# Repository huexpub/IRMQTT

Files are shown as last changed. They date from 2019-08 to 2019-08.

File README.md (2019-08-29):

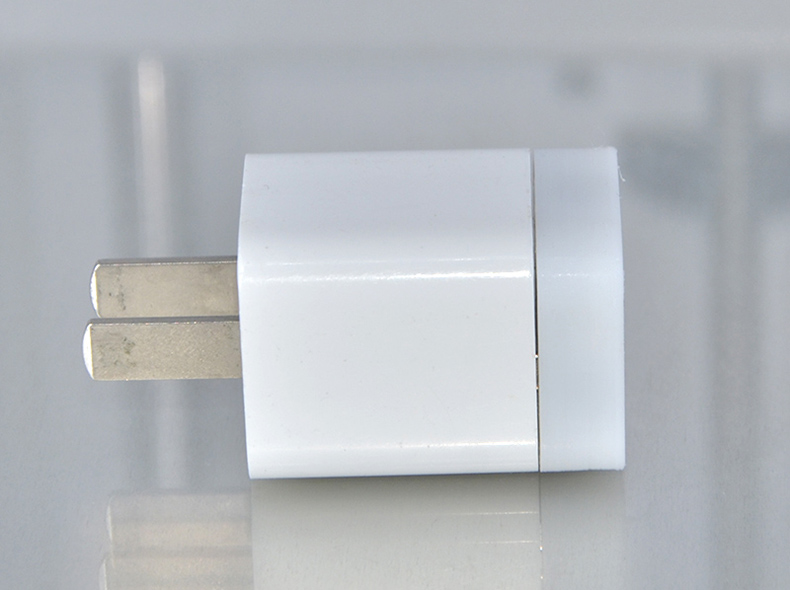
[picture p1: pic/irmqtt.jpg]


>>> 2019-08-29更新了可反馈性WEB使用说明及识别品牌

## 声明：
1. IRMQTT 是一个开源项目，源代码来自https://github.com/crankyoldgit/IRremoteESP8266，
2. IRMQTT PCB你可以自由的使用，并且制作分享与朋友交流，但严禁商业行为!

IRMQTT首贴：
https://bbs.iobroker.cn/thread-176-1-1.html

IRMQTT模块贴：
https://bbs.iobroker.cn/thread-221-1-1.html

IRMQTT支持列表：
https://github.com/crankyoldgit/IRremoteESP8266/blob/master/SupportedProtocols.md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

## 准备工作：
此次PCB模块为适应更高的通用性，以苹果绿点5V1A充电器为供电对象，最小化PCB板和硬件体积，合体后仅增加7.2mm的高度，一体感非常好!  由于体积定位，元件大量采用0402贴片，PCB面积仅21*20MM。

### PCB
本次PCB文件单体制造难度较大，新手尽量转移到ESP12F项目和ESP01F改装模块！高手可进

项目地址: https://github.com/huexpub/IRMQTT

* 分支包含ESP01F文件和ESP12F文件，默认为IRMQTT USB公插版本，
* 固件目前测试可以通用，如果内部为ESP01F，会有OTA文件限制！
* 刷机均需要1.27夹具或者焊接线材

### 贴装
PCB贴装，请控制好你的烙铁温度，保持300以内，针对发射贴片，请避免长时间操作

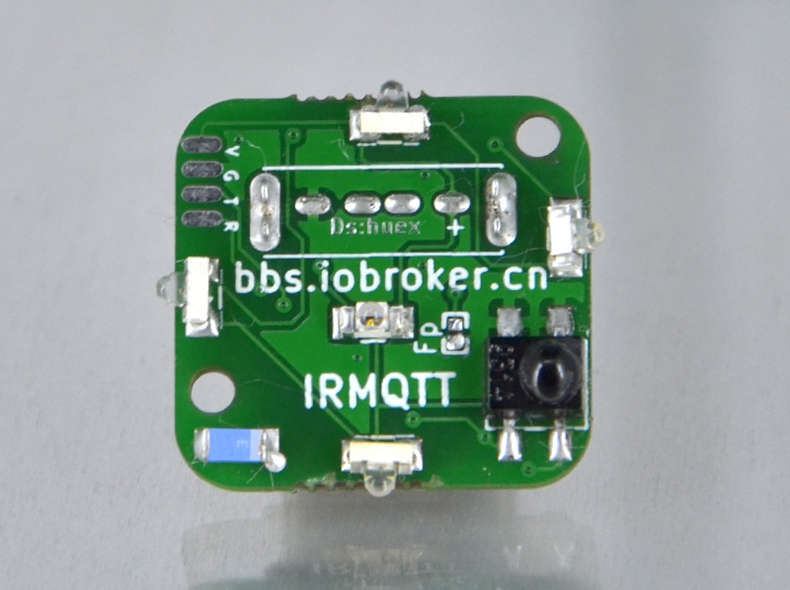
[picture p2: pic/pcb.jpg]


* 保持发射贴片丝印标记正确，除中心发射元件，其它保持45度角以得到更好的发射范围
* 由于接收元件外露在3D外壳之外，请确保元件正中，否则外壳无法安装

### 刷机

由于空间较小，刷机TTL为4P*1.27MM 故，你需要特殊的工具，比SOP8，SOP16刷机夹，1.27测试针，或者自己焊接线刷机，刷机后，后期均由OTA完成更新！PCB正面，FP脚为0-GND的短接点，短接后，ESP进入下载模式，刷机完成后，请去除短接！

### 3D
 3D外壳为上、下沉方式，需要M2沉头螺丝两颗，目前设计的螺丝帽直径最大为4.5MM 沉头内六角螺丝。
 
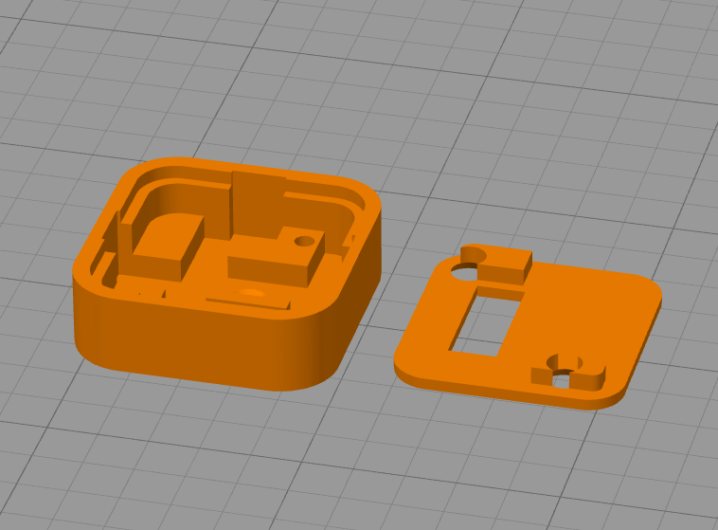
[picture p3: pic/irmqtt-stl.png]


## 安装使用：
软件采用WIFIMANAGER配网，上电后，搜索IRMQTT热点，连接上，转入配网WEB页面，未弹出请尝试访问192.168.4.1地址

### 配网

>请务必保证MQTT服务器地址正确，否则可能无法进入WEB页面，并且无法重新配置！

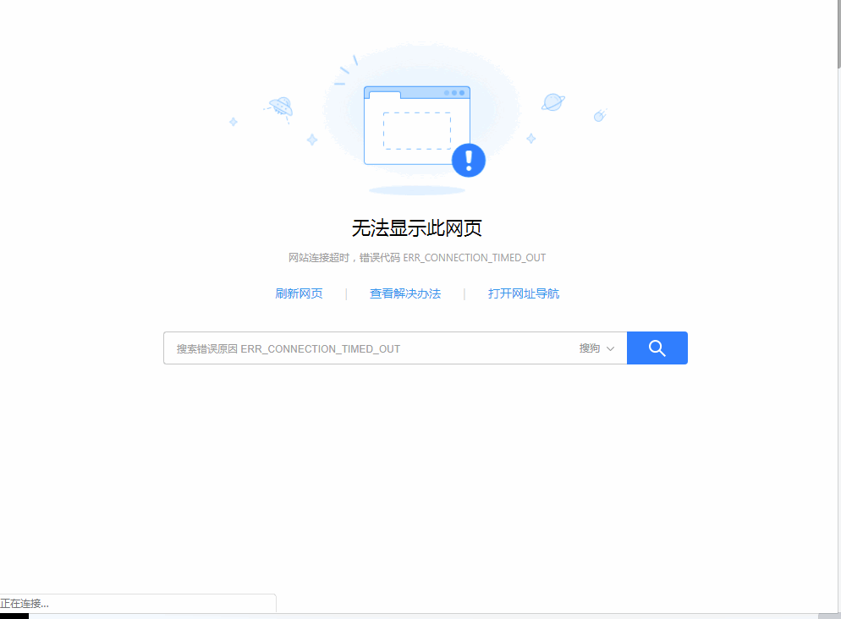
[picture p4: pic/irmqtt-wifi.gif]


### 使用
进入配置的IRMQTT设备IP WEB，页面如下：

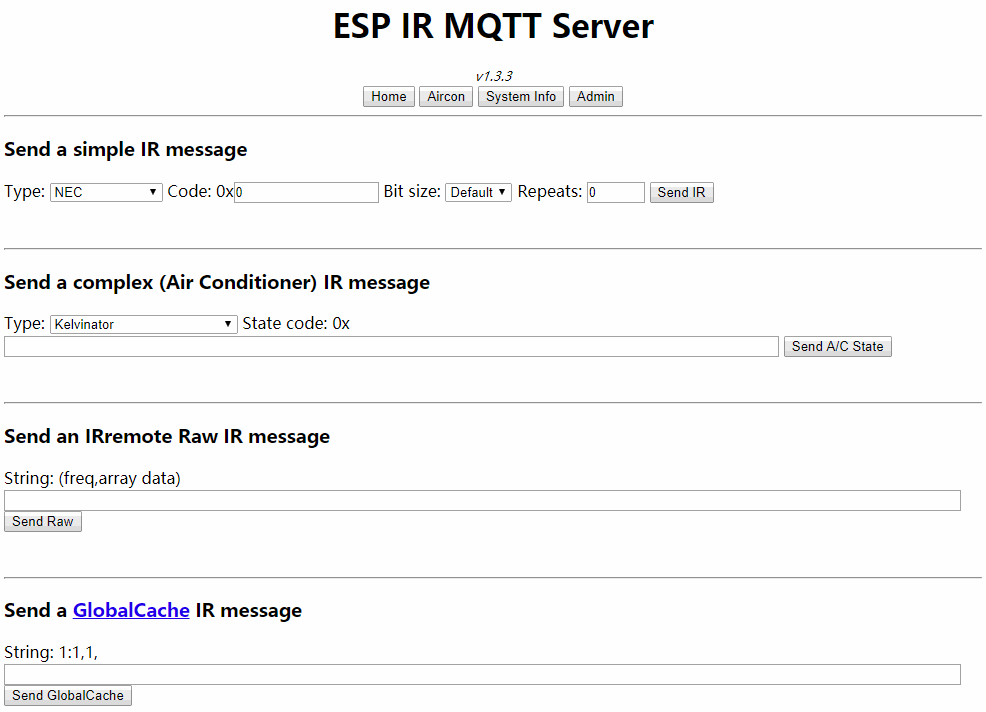
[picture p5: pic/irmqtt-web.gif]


选择对应的空调型号，模式，电源，温度，并点击 UPDATE/SEND，空调有反应后，视为有效型号，若无反应，请对应尝试model 1-6子设备型号，如均无反应，可能不被支持。

### 反馈
如何知道IRMQTT模块是否已经能正常的反馈呢，你可以使用MQTT工具监听。如下图GIF演示！

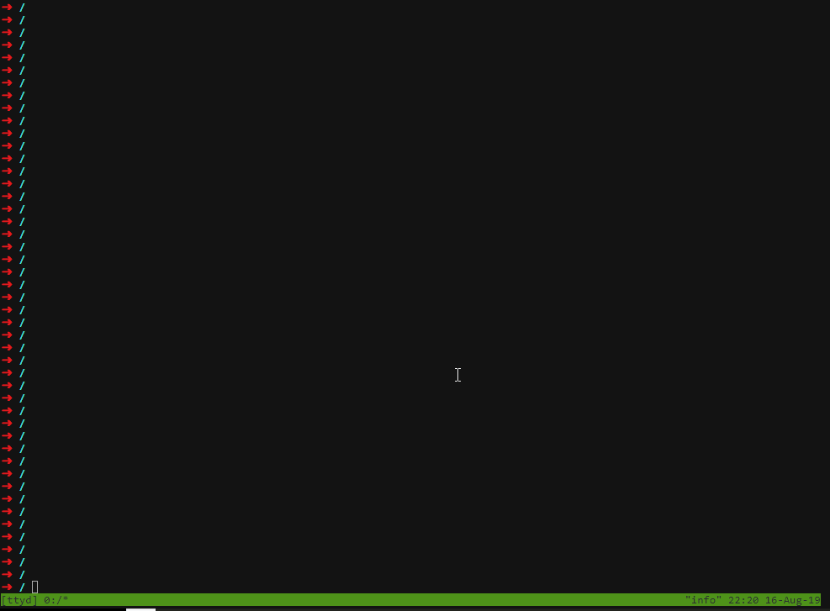
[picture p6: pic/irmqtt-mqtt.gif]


*  默认连接上MQTT后，出来的型号和设备等是默认生成的，不是接收到的
* 操作之后能出现ON OFF和有效的数据源，视为可反馈，
* 关于监听工具，你可以使用docker 镜像  huex/webzsh:armbian (https://mysensor.pub/gateway/webzsh/)

### 识别

```
enum decode_type_t {
  UNKNOWN = -1,
  UNUSED = 0,
  RC5,
  RC6,
  NEC,
  SONY,
  PANASONIC,  // (5)
  JVC,
  SAMSUNG,
  WHYNTER,
  AIWA_RC_T501,
  LG,  // (10)
  SANYO,
  MITSUBISHI,
  DISH,
  SHARP,
  COOLIX,  // (15)
  DAIKIN,
  DENON,
  KELVINATOR,
  SHERWOOD,
  MITSUBISHI_AC,  // (20)
  RCMM,
  SANYO_LC7461,
  RC5X,
  GREE,
  PRONTO,  // Technically not a protocol, but an encoding. (25)
  NEC_LIKE,
  ARGO,
  TROTEC,
  NIKAI,
  RAW,  // Technically not a protocol, but an encoding. (30)
  GLOBALCACHE,  // Technically not a protocol, but an encoding.
  TOSHIBA_AC,
  FUJITSU_AC,
  MIDEA,
  MAGIQUEST,  // (35)
  LASERTAG,
  CARRIER_AC,
  HAIER_AC,
  MITSUBISHI2,
  HITACHI_AC,  // (40)
  HITACHI_AC1,
  HITACHI_AC2,
  GICABLE,
  HAIER_AC_YRW02,
  WHIRLPOOL_AC,  // (45)
  SAMSUNG_AC,
  LUTRON,
  ELECTRA_AC,
  PANASONIC_AC,
  PIONEER,  // (50)
  LG2,
  MWM,
  DAIKIN2,
  VESTEL_AC,
  TECO,  // (55)
  SAMSUNG36,
  TCL112AC,
  LEGOPF,
  MITSUBISHI_HEAVY_88,
  MITSUBISHI_HEAVY_152,  // 60
  DAIKIN216,
  SHARP_AC,
  GOODWEATHER,
  INAX,
  DAIKIN160,  // 65
  NEOCLIMA,
  DAIKIN176,
  DAIKIN128,
  AMCOR,
  DAIKIN152,  // 70
  
```

以上为可识别的代码列表，你可以进入IRMQTT-WEB页面 SYSTEM-INFO页 找到 Last IR Received: 47,0,0 (9 hours 53 minutes 58 seconds ago)

得到47,0,0 代表是得到47序号的对应品牌属性值，对照上文，为LUTRON，部分空调反馈的品牌未必是品牌自身对应，这可能是该品牌有代工或者被代工的。如果是其它家用电器，电视等，这些基本被统一，多数为三星，索尼，松下协议或者标准RC协议不必对照本身品牌！

### 接入
由于采用标准MQTT协议，并且作者以Homeassistant为蓝本输出消息，故，你可以使用IRMQTT-WEB控制台发送 MQTT discovery 让平台自动发现即可，也可以手动配置，配置如下：

```

climate:
  - platform: mqtt
    name: zwaircon
    modes:
      - "off"
      - "auto"
      - "cool"
      - "heat"
      - "dry"
    fan_modes:
      - "auto"
      - "min"
      - "low"
      - "medium"
      - "high"
      - "max"
    swing_modes:
      - "off"
      - "auto"
      - "highest"
      - "high"
      - "middle"
      - "low"
    power_command_topic: "ir_server/ac/cmnd/power"
    mode_command_topic: "ir_server/ac/cmnd/mode"
    mode_state_topic: "ir_server/ac/stat/mode"
    temperature_command_topic: "ir_server/ac/cmnd/temp"
    temperature_state_topic: "ir_server/ac/stat/temp"
    fan_mode_command_topic: "ir_server/ac/cmnd/fanspeed"
    fan_mode_state_topic: "ir_server/ac/stat/fanspeed"
    current_temperature_topic: "tele/bksensor/SENSOR"
    current_temperature_template: "{{ value_json['SI7021'].Temperature }}"
    swing_mode_command_topic: "ir_server/ac/cmnd/swingv"
    swing_mode_state_topic: "ir_server/ac/stat/swingv"
    min_temp: 16
    max_temp: 30
    temp_step: 1
    retain: false
    
```
*  current_temperature_topic 和 current_temperature_template 为外部引用温度，这里采用了JSON格式的消息
*  请依据你的空调实际情况修改对应的菜单

### OTA
由于ESP01F flash只有1MB，实际固件不能超过467KB，但由于按开源编译，固件至少490K，造成由于空间不够无法在线更新，故我们只能曲线升级，在不破坏SPIIFS的情况下，先上传一个只有WEB-UPDATE功能的迷你型固件，该固件也采用WIFIMANAGER配置 网，并且能继承原有配置，升级后重新打开IP，进入WEB，选择最新的IMQTT固件升级即可

总结即： OTA--MINI 固件--正常固件

以下为演示：
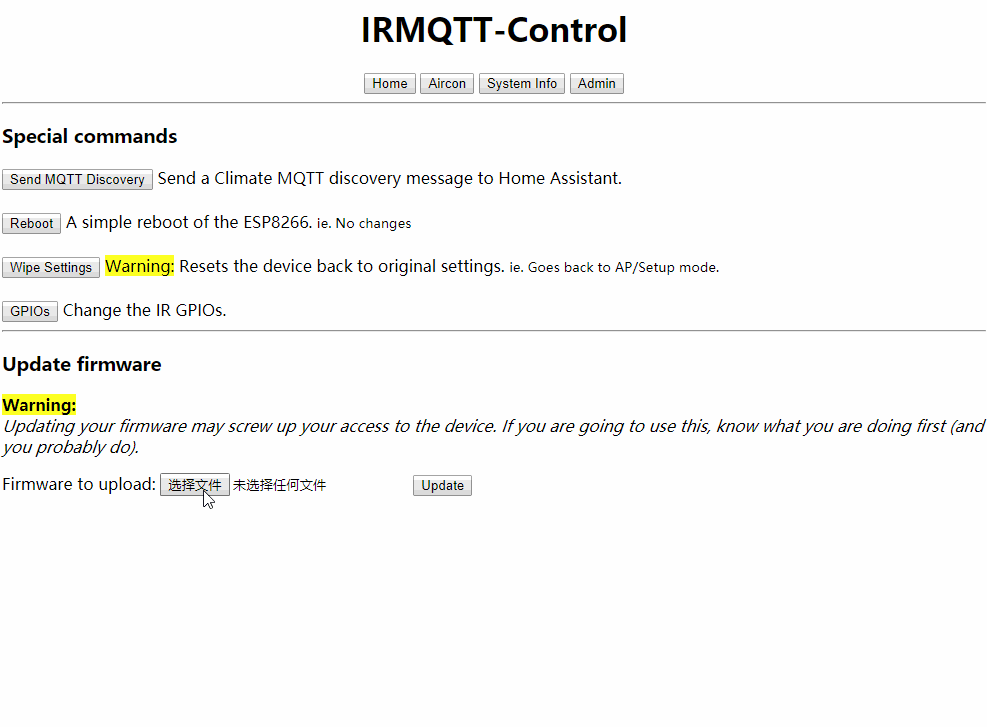
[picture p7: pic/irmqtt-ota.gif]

  
## SMT开车
  此次为了方便各位，目前已经将PCB 容阻元件、三极管、LED、LDO 采用 SMT 小批量产，到手只需要焊接发射元件、接收元件、USB、天线贴片、ESP01，极容易操作的元件部分！方便能DIY并且有3D打印机的小伙伴!
  
链接：https://item.taobao.com/item.htm?spm=a1z10.1-c.w4023-7677041950.2.57033a0cMouRqm&id=600537216286

*  成品涉及到3D打印，由于打印消耗时间和人工，故发货时间7天内
*  淘宝不经常在线，如果你有疑问和好的建议尽量在论坛或者ioBroker群MYSENSOR群@HUEX

## Q&A

- 1.购买单PCB文件，我还要购买哪些材料？
A: 安信可ESP01F 、BOM表中的EVERLIGHT台产亿光 IR26-61C 发射贴片、接收元件H638T，2.4G天线RFANT3216-Z。

- 2.空调在列表中，但无法发射？
A: 请先使用MQTT监测是否遥控有接收到数据，如果有数据，那么你发射的型号可能不对，特别是像美的，格力，等在海外有代工或者授权品牌，采用的，你可能需要使用其它品牌型号，比如COOLIX、ELECTRA_AC等。如果你接收都没有任何消息，那么很遗憾，至少源码暂时可能无法支持。

- 3.部分操作码不正常？
A: 出现这个情况，你可以尝试更换其它MODEL试试，1-6每个都试一下，如果问题依然，那么需要向作者提交ISSUES来解决，你需要提交原始码，原始操作，有差异化的信息，然后一并提交，具体提交办法你可以参考作者源码的入口。

- 4.有支持其它电源吗？
A. 理论上体积大于25*25mm的电源都可以3D画图解决，但手头暂时无其它电源，也没有额外的精力设计制作，暂时不扩充，你可以自行设计！

- 5.固件我可以自己编译上传吗？
A.没有问题，按上述OTA操作，先上传MINI固件，然后上传最新的即可。

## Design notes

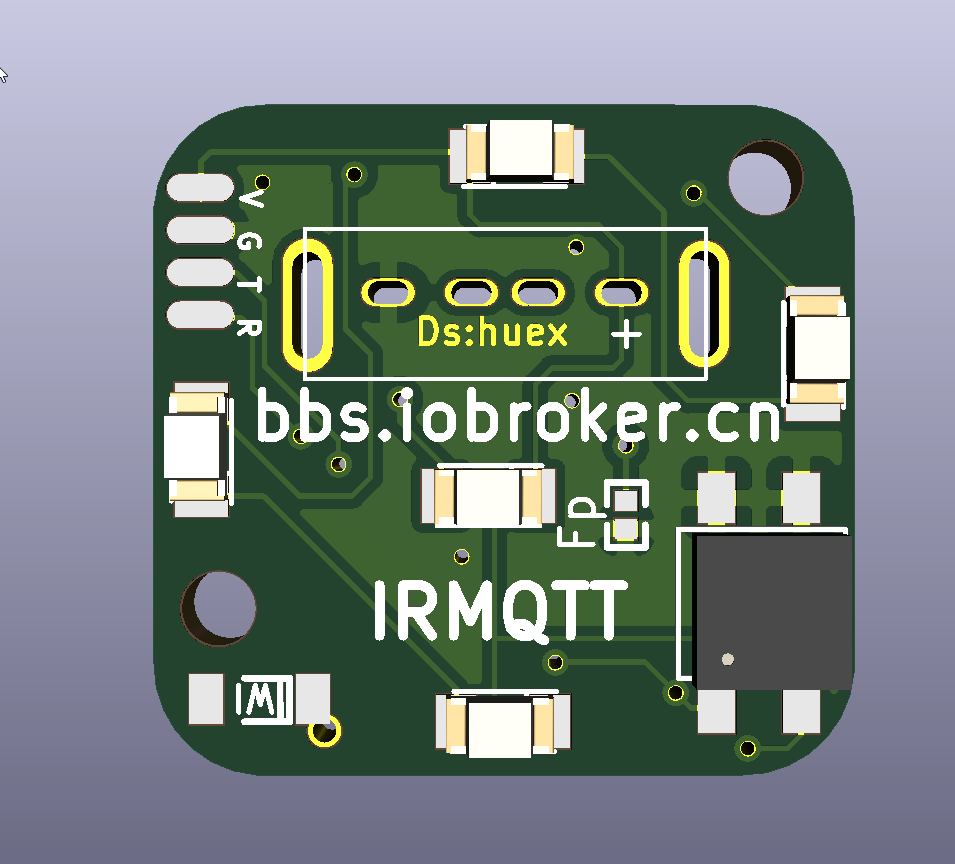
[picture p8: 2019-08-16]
pcb.png

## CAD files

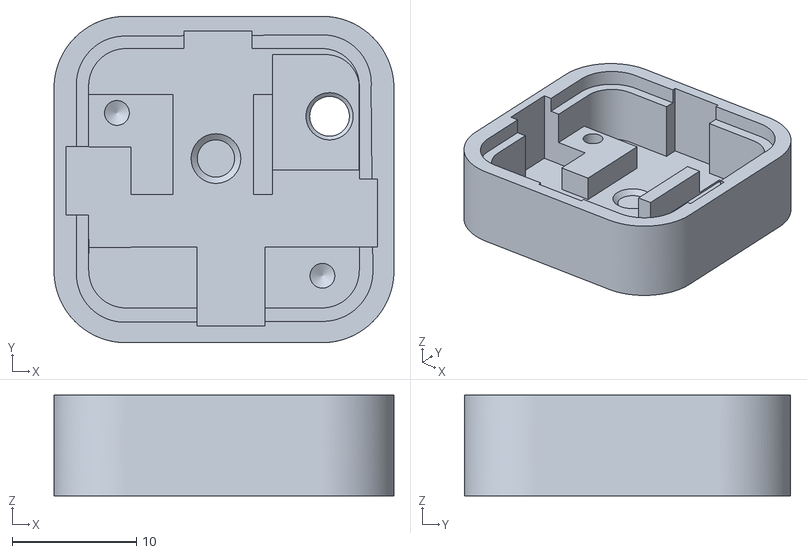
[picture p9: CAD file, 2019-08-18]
stl/PIR v69.stl
27.4 x 26.3 x 8.10

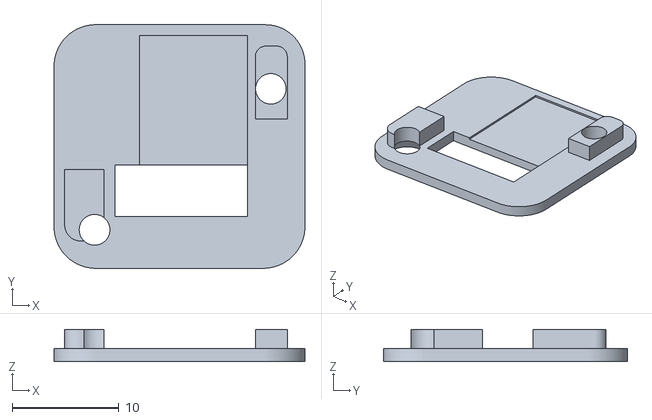
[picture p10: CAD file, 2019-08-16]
stl/IR-B v30.stl
23.5 x 22.8 x 3.00

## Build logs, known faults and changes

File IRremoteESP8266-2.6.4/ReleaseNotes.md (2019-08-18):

# Release Notes

## _v2.6.4 (20190726)_

**[Bug Fixes]**
- Fix some swing problems with the Mitsubishi HAVC protocol (#831)
- Fix parameter ordering for Gree in common a/c code. (#815)
- Fix parameters for Coolix in IRac::sendAc() (#829)
- IRMQTTServer: Fix sending >64 bit codes. (#811)

**[Features]**
- Daikin128: Full detailed support & common a/c support. (#832)
- Midea: Support native temp units of Celsius & SwingV. (#823)
- Gree: Support `YBOFB` models and bug fix. (#815)
- Pioneer: Fix sendPioneer with Pioneer specific timings (#830)
- Daikin128: Initial support for Daikin 17 Series/BRC52B63 (#828)
- Coolix: Better `toCommon()` support. (#825)
- Experimental detailed support for Daikin 176 bits (#816)
- Add setting of output options to A/C classes. (#808)
- Add invert flag support to Samsung AC (#807)

**[Misc]**
- Daikin176: making some change on Daikin176 to work with IRMQTTServer (#826)
- Reduce duplicate code to save (3K+) space. (#813)
- Daikin176: Experiment Daikin176bits with IRMQTTServer (#824)
- Update platformio.ini files for PlatformIO v4.0.0 (#812)
- Change repo URLs to new location. (#806)
- Move `htmlEscape()` to the IRutils namespace (#801)

## _v2.6.3 (20190704)_

**[Bug Fixes]**
- IRMQTTServer: REPLAY_DECODED_AC_MESSAGE not working. (#784, #797)
- ESP32: Ensure `IRrecv`'s GPIO is set to input mode. (#774)

**[Features]**
- IRMQTTServer: Show available sketch space for OTA uploads. (#795)
- Experimental detailed support for Electra/AUX protocol (#788)
- IRMQTTServer: Ability to resend existing climate state via MQTT & HTTP (#784)
- Daikin160: Add detailed & common a/c support. (#777)
- Experimental detailed support for Neoclima protocol. (#767)
- Gree: add WiFi and IFeel bits (#770)
- Handle A/Cs with toggles better. (#758)
- IRMQTTServer: Allow sending/receiving climate via JSON over MQTT. (#763)

**[Misc]**
- Move converting of IR A/C messages out of example code. (#798)
- Reduce example code size and complexity (#790)
- Change `ControlSamsungAC` example to not use `sendExtended()` (#792)
- IRMQTTServer: Add MQTT_CLIMATE_IR_SEND_ON_RESTART compile-time flag. (#784)
- Refactor A/C's toString()'s to reduce code size. Saves ~3.5k (#782)
- Add sanity tests for unexpected conditions in IRrecv. (#773)
- IRMQTTServer: Fixed the HA config documentation (missing '-') (#776)
- Improve `mkkeywords` tool. (#766)
- Refactor with generic decode routines in `IRrecv` class. Saves ~7k. (#765)

## _v2.6.2 (20190616)_

**[Features]**
- Initial support for the ESP32 architecture & boards. (#742)
- Add changable GPIO settings to IRMQTTServer. (#730)
- IRMQTTServer: Enforce a repeat for all Coolix calls (#752)
- Basic DAIKIN 160bit send and decode. (#754)
- Add example code for a Smart(er) IR Repeater. (#740)
- Enforce Samsung A/C Quiet & Powerful mutual exclusivity.

**[Misc]**
- IRMQTTServer: Add some memory alloc safety checks. (#749)
- Move some ToString() functions to IRac.cpp (#748)
- Increase tolerance value for TCL112AC protocol. (#745)
- Fix compiler warning in IRutils_test.cpp (#756)
- Scrape Supported Protocols and generate SupportedProtocols.md (#755)
- Make supported device info more organised. (#753)

## _v2.6.1 (20190609)_

**[Breaking Changes]**
- Major rework/breaking changes to Argo A/C support. (#705)

**[Bug Fixes]**
- Correct `set/getQuiet` for Samsung A/C (#736)
- Add missing `on/off()` to IRCoolixAC class. (#725)
- Daikin `set/getEye()` uses wrong bit. (#711)
- IRMQTTServer: Continue to use same Temperature units. (#710)
- Fixed a bug with `setMode()`/`getMode()` for HAIER_AC. (#705)

**[Features]**
- Add set/getPowerful for Samsung A/C (#736)
- Add `calibrate()` to all the A/C classes. (#735)
- IRMQTTServer: Add sequencing for sending MQTT IR commands. (#723)
- Add support for Fujitsu AR-REB1E & AR-JW2 remotes. (#718)
- Add Beta `decodeTrotec()` support. (#719)
- Add experimental `decodeArgo()` support. (#717)
- Support for Goodweather A/Cs. (#715)
- Add `DISABLE_CAPTURE_WHILE_TRANSMITTING` feature to IRMQTTServer. (#713)
- Support for Lixil Inax Toilet protocol. (#712)
- Add `set/getWeeklyTimerEnable()` to Daikin (#711)
- IRMQTTServer: Update Common A/C settings based on received IR messages. (#705)
- Add day of week to DAIKIN protocol (#699)
- Add limited support for Sharp A/C (#696)
- SAMSUNG_AC: Make sure special power mode messages are sent. (#695)
- Add `set/getPowerful()` (turbo) to DAIKIN216 (#693)

**[Misc]**
- Add kPeriodOffset for CPU Freq of 160MHz. (#729)
- Example code for a Dumb IR repeater. (#737)
- Update swing handling for Fujitsu A/Cs. (#724)
- Add function to convert `decode_results` to `sendRaw()` array. (#721)
- Attempt to reduce heap fragmentation from strings. (#707)
- Update Fujitsu A/C example code to safer settings (#716)
- Enforce better `const` usage in IRUtils. (#708)
- Attempt to reduce heap fragmentation by A/C `toString()`s. (#694)
- Minor changes to DAIKIN216 timings and features. (#693)

## _v2.6.0 (20190430)_

**[Bug Fixes]**
- Fixed problem where LG protocol used wrong duty cycle for repeat. (#687)
- Fix checksum calculation for Daikin protocols. (#678)
- Fix the byte array version of sendGree() (#684, #685)
- Fix artificial vs. real state creation on HaierAC. (#668, #671)
- Fix issues caused by having `MQTT_ENABLE` set to false. (#677)
- Fix compile problem when DEBUG is defined. (#673, #674)
- Fix Minor bug with MQTT_ENABLE False condition (#654)

**[Features]**
- Experimental support for DAIKIN216 (ARC433B69) (#690)
- Experimental support for Mitsubishi Heavy Industries A/Cs. (#660, #665, #667)
- Support more features of TCL A/C (#656)
- Add LEGO(TM) Power Functions IR protocol. (#655)
- Add Panasonic AC RKR model & Example (#649)
- DAIKIN/IRDaikinESP overhaul and add Comfort mode support. (#678)
  **WARNING**: Previous `sendDaikin()` calls may not work.
               Please recapture codes or use `kDaikinStateLengthShort` for
               `nbytes` in those calls.
- IRMQTTServer: Move MQTT server and other parameters to WifiManager. (#680)
  **WARNING**: Previous users may need to fully wipe/reset the
               SPIFFS/WifiManager settings by visiting
               `http://<your_esp8266's_ip_address>/reset` prior to or
               after update.
- Add Wifi filtering options to IRMQTTServer. (#679)
- Add advanced aircon/climate functionality to IRMQTTServer (#677)
- Initial prototype of a common interface for all A/Cs. (#664)
- Improve MQTT topic usage for feedback messages. (#663)
- Add multiple independent GPIO sending support via MQTT. (#661)

**[Misc]**
- Adjust kGreeHdrSpace to 4500 (#684, #686)
- Add Home Assistant mqtt climate instructions. (#682)
- Implement htmlEscape() to prevent XSS etc. (#681)
- Add F() Macros (#670)
- Update Daikin2's Cool mode min temp to 18C (#658)
- Change per byte bit-order in Electra protocol. (#648)
- Improve Daikin2 power on/off. (#647)

## _v2.5.6 (20190316)_

**[Bug Fixes]**
- Fix Coolix A/C Class to handle special states better. (#633, #624)

**[Features]**
- Fix case style for recent A/C protocols. (#631)
- Update `IRsend::send()` to include all simple protocols. (#629, #628)
- Experimental basic support for 112 bit TCL AC messages (#627, #619)
- Add support for TECO AC (#622)
- Experimental support for Samsung 36 bit protocol (#625, #621)

**[Misc]**
- Set Coolix to default to 1 repeat. (#637, #636, #624, #439)
- Set Daikin2 modulation to 36.7kHz. (#635)
- Refactor IRVestelAC class to use portable code. (#617)
- Adjust Daikin2 timings and tolerance. (#616, #582)

## _v2.5.5 (20190207)_

**[Bug Fixes]**
- Fix decoding of Samsung A/C Extended messages. (#610)
- Fix IRMQTTServer example to work with GPIO0 as IR_RX (#608)
- Fix incorrect #define usage. (#597, #596)

**[Features]**
- Add deep decoding/construction of Daikin2 messages (#600)
- Added Old Vestel A/C support (56 Bits) with full functions. (#607)

**[Misc]**
- Add ControlSamsungAC example code. (#599)
- Add how to send a state/air-con to IRsendDemo.ino (#594)

## _v2.5.4 (20190102)_

**[Features]**
- Experimental basic support for 39 Byte Daikin A/C (#583)
- Handle send() repeats in A/C classes. Improve Coolix support. (#580)
- Add optional RX pin pullup and dump raw messages in IRMQTTServer.ino (#589)

**[Misc]**
- Make auto_analyse_raw_data.py work with Python3 (#581)
- Update CI/travis config due to esp8266 core 2.5.0 changes (#591)

## _v2.5.3 (20181123)_

**[Features]**
- Add deep support for the Hitachi 28-Byte A/C Protocol (#563)
- Deep decoding for Whirlpool A/C (#572)
- Improve security options for IRMQTTServer example. (#575)
- Require a changed firmware password before upload. (#576)

**[Misc]**
- Add missing '}' in output of Auto analyse. (#562)
- Make A/C example code a bit more simple. (#571)

## _v2.5.2 (20181021)_

**[Bug Fixes]**
- Add missing send() method to IRPanasonicAC class. (#545)
- Add missing sendWhirlpoolAC() to IRMQTTServer.ino (#558)

**[Features]**
- Add IR receiving support to IRMQTTServer. (#543)
- Pioneer support (#547)
- Add support for a second LG protocol variant. (#552)
- Support for short Panasonic A/C messages. (#553)
- Add support for Panasonic CKP series A/Cs. (#554)
- Experimental timer/clock support for Panasonic A/Cs. (#546)
- Add Made With Magic (MWM) support (#557)

**[Misc]**
- Grammar and typo fixes (#541, #549)
- Increase Panasonic A/C message tolerances. (#542)
- Added command mode2_decode in tools/ (#557)
- General code style cleanup (#560)

## _v2.5.1 (20181002)_

**[Bug Fixes]**
- Correct the byte used for Samsung AC Swing. (#529)
- Fix not sending Samsung A/C messages in IRMQTTServer. (#529)

**[Features]**
- Experimental support for Electra A/C messages. (#528)
- Experimental support for Panasonic A/C messages. (#535)
- Samsung A/C fixes & improvements (#529)
- IRMQTTServer v0.6.0 (#530)

**[Misc]**
- Change required WifiManager lib version to v0.14
- Add alias for RAWTICK to kRawTick. (#535)
- Update sendLutron() status. (#515)
- Remove leftover debug message in IRrecvDumpV2 (#526)

## _v2.5.0 (20180919)_

**[Bug Fixes]**
- Fix HTML menu error for GICABLE in IRMQTTServer. (#516)
- Fix Mitsubishi A/C mode setting. (#514)
- Add missing ',' in auto analyse tool generated code. (#513)
- Fix Fujitsu checksum validation. (#501)
- Remove errant Repeat debug statement in IRMQTTServer. (#507)

**[Features]**
- Mitsubishi A/C decode improvements. (#514)
- Basic support for Whirlpool A/C messages. (#511)
- Basic support for Samsung A/C messages. (#512)
- Experimental support for detailed Samsung A/C messages. (#521)
- Experimental support for detailed Coolix A/C messages. (#518)
- Experimental support for Lutron protocol. (#516)
- Calculate and use average values for timings in analysing tool. (#513)

**[Misc]**
- Style change from using #define's for constants to `const kConstantName`.
- Improve the JVC example code.

## _v2.4.3 (20180727)_

**[Bug Fixes]**
- Handle Space Gaps better in auto analyse tool. (#482)
- Correct min repeat for GICABLE in IRMQTTServer. (#494)

**[Features]**
- Add static IP config option to IRMQTTServer (#480)
- Full decoding/encoding support for the Haier YRW02 A/C. (#485 #486 #487)

**[Misc]**
- Update LG (28-bit) HDR mark and space timings. (#492)
- Spelling and grammar fixes (#491)

## _v2.4.2 (20180601)_

**[Bug Fixes]**
- Timing Fix: Update the period offset compensation.

**[Features]**
- Improvements for IRMQTTServer example (#466)

## _v2.4.1 (20180520)_

**[Bug Fixes]**
- Fix crash in IRMQTTServer when compiled under Arduino IDE. (#455)
- Default bit length not set for RCMM in IRMQTTServer example. (#456)
- Bad acknowledgements for some A/C protocols in IRMQTTServer example. (#460)

**[Features]**
- Allow disabling the use of delay() calls. (#450)
- Initial support for G.I. Cable protocol. (#458)
- Support of Hitachi A/C 13 & 53 byte messages. (#461)

**[Misc]**
- Auto Analyse Raw Data script converted to Python. (#454)

## _v2.4.0 (20180407)_

**[Bug Fixes]**
- Add missing WiFi.begin() call to IRGCTCPServer example. (#433)
- Add missing sendHaierAC() to IRMQTTServer example. (#434 & #444)
- Make mqtt clientid unique in IRMQTTServer example. (#444)

**[Features]**

- Initial Mitsubishi projector protocol support. (#442)
- Experimental support of Hitachi A/C messages. (#445)
- Improve transmission pulse modulation support.
  Allow disabling of transmission frequency modulation.(#439)

**[Misc]**
- IRMQTTServer example improvements. (#444)

## _v2.3.3 (20180302)_

**[Bug Fixes]**
- Ensure the IR LED is off before we start. (#405)

**[Features]**
- Experimental decode support for Gree HVAC units (#397)
- Initial support for Haier A/Cs. (#409)
- Improve timing accuracy of unit tests. (#403)
- Rework matchData() to handle equal total data bit time protocols. (#408)

**[Misc]**
- Add startup text to IRrecvDumpV2 and IRrecvDemo (#412)
- Tweak timings on Fujitsu A/C header (#418)
- AutoAnalyseRawData.sh: Add some support for handling larger than 64 bit codes. (#419)
- Use better comments for send GPIO in examples. (#425)

## _v2.3.2 (20180126)_

**[Bug Fixes]**
- Integer underflow caused device not to respond in `sendJVC()` (#401)

**[Features]**
- Initial support for sending & receiving Carrier HVAC codes. (#387)
- Add Pronto HEX code support to _gc_decode_ tool. (#388)

**[Misc]**
- Make mDNS independent of MQTT in IRMQTTServer example code. (#390 #391)

## _v2.3.1 (20171229)_

**[Bug Fixes]**
- Setting `#define SEND_FUJITSU_AC false` caused a compilation error (#375)
- Integer underflow caused huge `space()` in `sendGeneric()` (#381)

**[Features]**
- Support sending & receiving Lasertag codes. (#374)
- Reduce the library footprint by using a new `sendGeneric()` routine. (#373)

**[Misc]**
- Lots of grammar & typo fixes. (#378)
- Update keywords.txt for Arduino IDE users (#371)
- Update pins in examples so they are compatible with Adafruit boards. (#383)

## _v2.3.0 (20171208)_

**[Bug Fixes]**
- Panasonic-based protocols had incorrect message gap. (#358)
- Formatting error for large rawData values in example code. (#355)
- Off-by-one error in payload_copy malloc. (#337)
- Off-by-one error in unit test helper routines (#363)

**[Features]**
- Support sending and receiving Midea A/C codes.
- Support for receiving Kelvinator A/C codes. (#332)
- Support more operation features for Daikin A/Cs.
- Support for decoding Daikin A/Cs.
- Support sending and receiving Toshiba A/Cs. (#333)
- Support sending and receiving AR-DB1 Fujitsu A/C codes. (#367)
- Add new AutoAnalyseRawData.sh & RawToGlobalCache.sh tools (#345) (#343)
- Support for MagiQuest wands. (#365)

**[Misc]**
- Add checksum verification to Kelvinator A/C decodes. (#348)
- Changes to the threshold reporting of UNKNOWN messages (#347)
- Major re-work of Daikin A/C support.
- Sending for all A/Cs added to MQTT example code.
- MQTT example code improvements. (#334)
- IRrecvDumpV2 significant output improvements. (#363)
- Improved unit test coverage for the library.

## _v2.2.1 (20171025)_

**[Features]**
- Support for sending and decoding Nikai TV messages. (#311, #313)
- gc_decode: External utility to decode Global Cache codes. (#308, #312)
- IRMQTTServer: Example code to send IR messages via HTTP & MQTT. (#316, #323)
- Improve converting 64bit values to hexadecimal. (#318)

**[Misc]**
- IRrecvDump.ino code is now deprecated. Use IRrecvDumpV2.ino instead. (#314)

## _v2.2.0 (20170922)_

**[Bug Fixes]**
- Add printing output of RC-MM and RC-5X protocols in example code. (#284)
- LG timing improvements based on observations (#291)

**[Features]**
- Automatic capture timing calibration for some protocols. (#268)
- Support for creating & sending Trotec AC codes. (#279)
- Support for creating & sending Argo Ulisse 13 DCI codes. (#280 #300)
- Move to 2 microsecond timing resolution for capture of codes. (#287)
- Capture buffer changes:
- Size at runtime. (#276)
- Message timeout at runtime. (#294)
- Simplify creating & using a second buffer (#303)
- New example code:
  - Trotec A/C (#279)
  - LG A/C units (#289)
  - Argo Ulisse 13 DCI codes. (#300)

## _v2.1.1 (20170711)_

**[Bug Fixes]**
- GlobalCache incorrectly using hardware offset for period calc. (#267)

**[Features]**
- Support reporting of 'NEC'-like 32-bit protocols. e.g. Apple TV remote (#265)
- Add an example of sendRaw() to IRsendDemo.ino (#270)

## _v2.1.0 (20170704)_

**[Features]**
- Support for sending Pronto IR codes. (#248)
- Support for sending Fujitsu A/C codes. (#88)
- Minor improvements to examples.

## _v2.0.3 (20170618)_

**[Bug fixes]**
- Capture buffer could become corrupt after large message, breaking subsequent decodes. (#253)

## _v2.0.2 (20170615)_

**[Bug fixes]**
- Correct decode issue introduced in v2.0.1 affecting multiple protocol decoders (#243)
- Correct post-message gap for the Panasonic protocol(s) (#245)
- Incorrect display of the decoded uint64_t value in the example code. (#245)

## _v2.0.1 (20170614)_

**[Bug fixes]**
- Decoding protocols when it doesn't detect a post-command gap, and there is no more data. (#243)
- Incorrect minimum size calculation when there is no post-command gap. (#243)

## _v2.0.0 - 64 bit support and major improvements (20170612)_

**[Misc]**
- This is almost a complete re-write of the library.

**[Features]**
- All suitable protocols now handle 64-bit data messages and are repeatable via an optional argument.
- Unit tests for all protocols.
- Far better and stricter decoding for most protocols.
- Address & command decoding for protocols where that information is available.
- Much more precise timing for generation of signals sent.
- Lower duty-cycles for some protocols.
- Several new protocols added, and some new sending and decoding routines for existing ones.
- Ability to optionally chose which protocols are included, enabling faster decoding and smaller code footprints if desired.
- Support for far larger capture buffers. (e.g. RAWLEN > 256)

**[Bug fixes]**
- Numerous bug fixes.

## _v1.2.0 (20170429)_

**[Features]**
- Add ability to copy IR capture buffer, and continue capturing. Means faster and better IR command decoding.
- Reduce IRAM usage by 28 bytes.
- Improve capture of RC-MM & Panasonic protocols.
- Upgrade IRrecvDumpV2 to new IR capture buffer. Much fewer corrupted/truncated IR messages.

## _v1.1.1 (20170413)_

**[Bug fixes]**
- Fix a reported problem when sending the LG protocol. Preemptive fix for possible similar cases.
- Fix minor issues in examples.

**[Features]**
- Add documentation to some examples to aid new people.
- Add ALPHA support for RC-MM protocol. (Known to be currently not 100% working.)

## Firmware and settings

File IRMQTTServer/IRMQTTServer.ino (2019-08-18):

/*
   Send & receive arbitrary IR codes via a web server or MQTT.
   Copyright David Conran 2016, 2017, 2018, 2019

   Copyright:
     Code for this has been borrowed from lots of other OpenSource projects &
     resources. I'm *NOT* claiming complete Copyright ownership of all the code.
     Likewise, feel free to borrow from this as much as you want.

   NOTE: An IR LED circuit SHOULD be connected to the ESP if
         you want to send IR messages. e.g. GPIO4 (D2)
         A compatible IR RX modules SHOULD be connected to ESP
         if you want to capture & decode IR nessages. e.g. GPIO14 (D5)
         See 'IR_RX' in IRMQTTServer.h.
         GPIOs are configurable from the http://<your_esp8266's_ip_address>/gpio
         page.

   WARN: This is *very* advanced & complicated example code. Not for beginners.
         You are strongly suggested to try & look at other example code first
         to understand how this library works.

   # Instructions

   ## Before First Boot (i.e. Compile time)
   - Disable MQTT if desired. (see '#define MQTT_ENABLE' in IRMQTTServer.h).

   - Site specific settings:
     o Search for 'CHANGE_ME' in IRMQTTServer.h for the things you probably
       need to change for your particular situation.
     o All user changable settings are in the file IRMQTTServer.h.

   - Arduino IDE:
     o Install the following libraries via Library Manager
       - ArduinoJson (https://arduinojson.org/) (Version >= 5.0 and < 6.0)
       - PubSubClient (https://pubsubclient.knolleary.net/)
       - WiFiManager (https://github.com/tzapu/WiFiManager)
                     (ESP8266: Version >= 0.14, ESP32: 'development' branch.)
     o You MUST change <PubSubClient.h> to have the following (or larger) value:
       (with REPORT_RAW_UNKNOWNS 1024 or more is recommended)
       #define MQTT_MAX_PACKET_SIZE 768
     o Use the smallest non-zero SPIFFS size you can for your board.
       (See the Tools -> Flash Size menu)

   - PlatformIO IDE:
       If you are using PlatformIO, this should already been done for you in
       the accompanying platformio.ini file.

   ## First Boot (Initial setup)
   The ESP board will boot into the WiFiManager's AP mode.
   i.e. It will create a WiFi Access Point with a SSID like: "ESP123456" etc.
   Connect to that SSID. Then point your browser to http://192.168.4.1/ and
   configure the ESP to connect to your desired WiFi network and associated
   required settings. It will remember these details on next boot if the device
   connects successfully.
   More information can be found here:
     https://github.com/tzapu/WiFiManager#how-it-works

   If you need to reset the WiFi and saved settings to go back to "First Boot",
   visit:  http://<your_esp8266's_ip_address>/reset

   ## Normal Use (After initial setup)
   Enter 'http://<your_esp8266's_ip_address/' in your browser & follow the
   instructions there to send IR codes via HTTP/HTML.
   Visit the http://<your_esp8266's_ip_address>/gpio page to configure the GPIOs
   for the IR LED(s) and/or IR RX demodulator.

   You can send URLs like the following, with similar data type limitations as
   the MQTT formating in the next section. e.g:
     http://<your_esp8266's_ip_address>/ir?type=7&code=E0E09966
     http://<your_esp8266's_ip_address>/ir?type=4&code=0xf50&bits=12
     http://<your_esp8266's_ip_address>/ir?code=C1A2E21D&repeats=8&type=19
     http://<your_esp8266's_ip_address>/ir?type=31&code=40000,1,1,96,24,24,24,48,24,24,24,24,24,48,24,24,24,24,24,48,24,24,24,24,24,24,24,24,1058
     http://<your_esp8266's_ip_address>/ir?type=18&code=190B8050000000E0190B8070000010f0
     http://<your_esp8266's_ip_address>/ir?repeats=1&type=25&code=0000,006E,0022,0002,0155,00AA,0015,0040,0015,0040,0015,0015,0015,0015,0015,0015,0015,0015,0015,0015,0015,0040,0015,0040,0015,0015,0015,0040,0015,0015,0015,0015,0015,0015,0015,0040,0015,0015,0015,0015,0015,0040,0015,0040,0015,0015,0015,0015,0015,0015,0015,0015,0015,0015,0015,0040,0015,0015,0015,0015,0015,0040,0015,0040,0015,0040,0015,0040,0015,0040,0015,0640,0155,0055,0015,0E40

   or

   Send a MQTT message to the topic 'ir_server/send' (or 'ir_server/send_0' etc)
   using the following format (Order is important):
     protocol_num,hexcode
       e.g. 7,E0E09966
            which is: Samsung(7), Power On code, default bit size,
                      default nr. of repeats.

     protocol_num,hexcode,bits
       e.g. 4,f50,12
            which is: Sony(4), Power Off code, 12 bits & default nr. of repeats.

     protocol_num,hexcode,bits,repeats
       e.g. 19,C1A2E21D,0,8
            which is: Sherwood(19), Vol Up, default bit size & repeated 8 times.

     30,frequency,raw_string
       e.g. 30,38000,9000,4500,500,1500,500,750,500,750
            which is: Raw (30) @ 38kHz with a raw code of
              "9000,4500,500,1500,500,750,500,750"

     31,code_string
       e.g. 31,40000,1,1,96,24,24,24,48,24,24,24,24,24,48,24,24,24,24,24,48,24,24,24,24,24,24,24,24,1058
            which is: GlobalCache (31) & "40000,1,1,96,..." (Sony Vol Up)

     25,Rrepeats,hex_code_string
       e.g. 25,R1,0000,006E,0022,0002,0155,00AA,0015,0040,0015,0040,0015,0015,0015,0015,0015,0015,0015,0015,0015,0015,0015,0040,0015,0040,0015,0015,0015,0040,0015,0015,0015,0015,0015,0015,0015,0040,0015,0015,0015,0015,0015,0040,0015,0040,0015,0015,0015,0015,0015,0015,0015,0015,0015,0015,0015,0040,0015,0015,0015,0015,0015,0040,0015,0040,0015,0040,0015,0040,0015,0040,0015,0640,0155,0055,0015,0E40
            which is: Pronto (25), 1 repeat, & "0000 006E 0022 0002 ..."
               aka a "Sherwood Amp Tape Input" message.

     ac_protocol_num,really_long_hexcode
       e.g. 18,190B8050000000E0190B8070000010F0
            which is: Kelvinator (18) Air Con on, Low Fan, 25 deg etc.
            NOTE: Ensure you zero-pad to the correct number of digits for the
                  bit/byte size you want to send as some A/C units have units
                  have different sized messages. e.g. Fujitsu A/C units.

     Sequences.
       You can send a sequence of IR messages via MQTT using the above methods
       if you separate them with a ';' character. In addition you can add a
       pause/gap between sequenced messages by using 'P' followed immediately by
       the number of milliseconds you wish to wait (up to a max of kMaxPauseMs).
         e.g. 7,E0E09966;4,f50,12
           Send a Samsung(7) TV Power on code, followed immediately by a Sony(4)
           TV power off message.
         or:  19,C1A28877;P500;19,C1A25AA5;P500;19,C1A2E21D,0,30
           Turn on a Sherwood(19) Amplifier, Wait 1/2 a second, Switch the
           Amplifier to Video input 2, wait 1/2 a second, then send the Sherwood
           Amp the "Volume Up" message 30 times.

     In short:
       No spaces after/before commas.
       Values are comma separated.
       The first value is always in Decimal.
       For simple protocols, the next value (hexcode) is always hexadecimal.
       The optional bit size is in decimal.
       CAUTION: Some AC protocols DO NOT use the really_long_hexcode method.
                e.g. < 64bit AC protocols.

     Unix command line usage example:
       # Install a MQTT client
       $ sudo apt install mosquitto-clients
       # Send a 32-bit NEC code of 0x1234abcd via MQTT.
       $ mosquitto_pub -h 10.0.0.4 -t ir_server/send -m '3,1234abcd,32'

   This server will send (back) what ever IR message it just transmitted to
   the MQTT topic 'ir_server/sent' to confirm it has been performed. This works
   for messages requested via MQTT or via HTTP.

     Unix command line usage example:
       # Listen to MQTT acknowledgements.
       $ mosquitto_sub -h 10.0.0.4 -t ir_server/sent

   Incoming IR messages (from an IR remote control) will be transmitted to
   the MQTT topic 'ir_server/received'. The MQTT message will be formatted
   similar to what is required to for the 'sent' topic.
   e.g. "3,C1A2F00F,32" (Protocol,Value,Bits) for simple codes
     or "18,110B805000000060110B807000001070" (Protocol,Value) for complex codes
   Note: If the protocol is listed as -1, then that is an UNKNOWN IR protocol.
         You can't use that to recreate/resend an IR message. It's only for
         matching purposes and shouldn't be trusted.

     Unix command line usage example:
       # Listen via MQTT for IR messages captured by this server.
       $ mosquitto_sub -h 10.0.0.4 -t ir_server/received

   Note: General logging messages are also sent to 'ir_server/log' from
         time to time.

   ## Climate (AirCon) interface. (Advanced use)
   You can now control Air Conditioner devices that have full/detailed support
   from the IRremoteESP8266 library. See the "Aircon" page for list of supported
   devices. You can do this via HTTP/HTML or via MQTT.

   NOTE: It will only change the attributes you change/set. It's up to you to
         maintain a consistent set of attributes for your particular aircon.

   TIP: Use "-1" for 'model' if your A/C doesn't have a specific `setModel()`
        or IR class attribute. Most don't. Some do.
        e.g. PANASONIC_AC, FUJITSU_AC, WHIRLPOOL_AC

   ### via MQTT:
   The code listen for commands (via wildcard) on the MQTT topics at the
   `ir_server/ac/cmnd/+` level, such as:
   i.e. protocol, model, power, mode, temp, fanspeed, swingv, swingh, quiet,
        turbo, light, beep, econo, sleep, filter, clean, use_celsius
   e.g. ir_server/ac/cmnd/power, ir_server/ac/cmnd/temp, etc.
   It will process them, and if successful and it caused a change, it will
   acknowledge this via the relevant state topic for that command.
   e.g. If the aircon/climate changes from power off to power on, it will
        send an "on" payload to "ir_server/ac/stat/power"

   There is a special command available to force the ESP to resend the current
   A/C state in an IR message. To do so use the `resend` command MQTT topic,
   e.g. `ir_server/ac/cmnd/resend` with a payload message of `resend`.
   There is no corresponding "stat" message update for this particular topic,
   but a log message is produced indicating it was received.

   NOTE: These "stat" messages have the MQTT retain flag set to on. Thus the
         MQTT broker will remember them until reset/restarted etc.

   The code will also periodically broadcast all possible aircon/climate state
   attributes to their corresponding "ir_server/ac/stat" topics. This ensures
   any updates to the ESP's knowledge that may have been lost in transmission
   are re-communicated. e.g. The MQTT broker being offline.
   This also helps with Home Assistant MQTT discovery.

   The program on boot & first successful connection to the MQTT broker, will
   try to re-acquire any previous aircon/climate state information and act
   accordingly. This will typically result in A/C IR message being sent as and
   saved state will probably be different from the defaults.

   NOTE: Command attributes are processed sequentially.
         e.g. Going from "25C, cool, fan low" to "27C, heat, fan high" may go
         via "27C, cool, fan low" & "27C, heat, fan low" depending on the order
         of arrival & processing of the MQTT commands.

   ### Home Assistant (HA) MQTT climate integration
   After you have set the Protocol (required) & Model (if needed) and any of
   the other misc aircon settings you desire, you can then add the following to
   your Home Assistant configuration, and it should allow you to
   control most of the important settings. Google Home/Assistant (via HA)
   can also control the device, but you will need to configure Home Assistant
   via it's documentation for that. It has even more limited control.
   It's far beyond the scope of these instructions to guide you through setting
   up HA and Google Home integration. See https://www.home-assistant.io/

   In HA's configuration.yaml, add:

   climate:
     - platform: mqtt
       name: Living Room Aircon
       modes:
         - "off"
         - "auto"
         - "cool"
         - "heat"
         - "dry"
         - "fan_only"
       fan_modes:
         - "auto"
         - "min"
         - "low"
         - "medium"
         - "high"
         - "max"
       swing_modes:
         - "off"
         - "auto"
         - "highest"
         - "high"
         - "middle"
         - "low"
         - "lowest"
       power_command_topic: "ir_server/ac/cmnd/power"
       mode_command_topic: "ir_server/ac/cmnd/mode"
       mode_state_topic: "ir_server/ac/stat/mode"
       temperature_command_topic: "ir_server/ac/cmnd/temp"
       temperature_state_topic: "ir_server/ac/stat/temp"
       fan_mode_command_topic: "ir_server/ac/cmnd/fanspeed"
       fan_mode_state_topic: "ir_server/ac/stat/fanspeed"
       swing_mode_command_topic: "ir_server/ac/cmnd/swingv"
       swing_mode_state_topic: "ir_server/ac/stat/swingv"
       min_temp: 16
       max_temp: 32
       temp_step: 1
       retain: false
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
void loop(void) {
  server.handleClient();  // Handle any web activity

#if MQTT_ENABLE
  uint32_t now = millis();
  // MQTT client connection management
  if (!mqtt_client.connected()) {
    if (wasConnected) {
      lastDisconnectedTime = now;
      wasConnected = false;
      mqttDisconnectCounter++;
    }
    // Reconnect if it's longer than kMqttReconnectTime since we last tried.
    if (now - lastReconnectAttempt > kMqttReconnectTime) {
      lastReconnectAttempt = now;
      debug("client mqtt not connected, trying to connect");
      // Attempt to reconnect
      if (reconnect()) {
        lastReconnectAttempt = 0;
        wasConnected = true;
        if (boot) {
          mqttLog("IRMQTTServer " _MY_VERSION_ " just booted");
          boot = false;
        } else {
          mqttLog(String(
                    "IRMQTTServer just (re)connected to MQTT. Lost connection about "
                    + timeSince(lastConnectedTime)).c_str());
        }
        lastConnectedTime = now;
        debug("successful client mqtt connection");
        if (lockMqttBroadcast) {
          // Attempt to fetch back any Climate state stored in MQTT retained
          // messages on the MQTT broker.
          mqttLog("Started listening for previous state.");
          climate_prev = climate;  // Make a copy so we can compare afterwards.
          subscribing(MqttClimateStat + '+');
          statListenTime.reset();
        }
      }
    }
  } else {
    // MQTT loop
    lastConnectedTime = now;
    mqtt_client.loop();
    if (lockMqttBroadcast && statListenTime.elapsed() > kStatListenPeriodMs) {
      unsubscribing(MqttClimateStat + '+');
      mqttLog("Finished listening for previous state.");
      if (IRac::cmpStates(climate, climate_prev)) {  // Something changed.
        mqttLog("The state was recovered from MQTT broker. Updating.");
        sendClimate(climate_prev, climate, MqttClimateStat,
                    true, false, false, MQTT_CLIMATE_IR_SEND_ON_RESTART);
        lastClimateSource = F("MQTT (via retain)");
      }
      lockMqttBroadcast = false;  // Release the lock so we can broadcast again.
    }
    // Periodically send all of the climate state via MQTT.
    doBroadcast(&lastBroadcast, kBroadcastPeriodMs, climate, false, false);
  }
#endif  // MQTT_ENABLE
#if IR_RX
  // Check if an IR code has been received via the IR RX module.
#if REPORT_UNKNOWNS
  if (irrecv != NULL && irrecv->decode(&capture)) {
#else  // REPORT_UNKNOWNS
  if (irrecv != NULL && irrecv->decode(&capture) &&
      capture.decode_type != UNKNOWN) {
#endif  // REPORT_UNKNOWNS
    lastIrReceivedTime = millis();
    lastIrReceived = String(capture.decode_type) + kCommandDelimiter[0] +
                     resultToHexidecimal(&capture);
#if REPORT_RAW_UNKNOWNS
    if (capture.decode_type == UNKNOWN) {
      lastIrReceived += ";";
      for (uint16_t i = 1; i < capture.rawlen; i++) {
        uint32_t usecs;
        for (usecs = capture.rawbuf[i] * kRawTick; usecs > UINT16_MAX;
             usecs -= UINT16_MAX) {
          lastIrReceived += uint64ToString(UINT16_MAX);
          lastIrReceived += ",0,";
        }
        lastIrReceived += uint64ToString(usecs, 10);
        if (i < capture.rawlen - 1)
          lastIrReceived += ",";
      }
    }
#endif  // REPORT_RAW_UNKNOWNS
    // If it isn't an AC code, add the bits.
    if (!hasACState(capture.decode_type))
      lastIrReceived += kCommandDelimiter[0] + String(capture.bits);
#if MQTT_ENABLE
    mqtt_client.publish(MqttRecv.c_str(), lastIrReceived.c_str());
    mqttSentCounter++;
    debug("Incoming IR message sent to MQTT:");
    debug(lastIrReceived.c_str());
#endif  // MQTT_ENABLE
    irRecvCounter++;
#if USE_DECODED_AC_SETTINGS
    if (decodeCommonAc(&capture)) lastClimateSource = F("IR");
#endif  // USE_DECODED_AC_SETTINGS
  }
#endif  // IR_RX
  delay(100);
}

// Arduino framework doesn't support strtoull(), so make our own one.
uint64_t getUInt64fromHex(char const *str) {
  uint64_t result = 0;
  uint16_t offset = 0;
  // Skip any leading '0x' or '0X' prefix.
  if (str[0] == '0' && (str[1] == 'x' || str[1] == 'X'))
    offset = 2;
  for (; isxdigit((unsigned char)str[offset]); offset++) {
    char c = str[offset];
    result *= 16;
    if (isdigit(c)) /* '0' .. '9' */
      result += c - '0';
    else if (isupper(c)) /* 'A' .. 'F' */
      result += c - 'A' + 10;
    else /* 'a' .. 'f'*/
      result += c - 'a' + 10;
  }
  return result;
}

// Transmit the given IR message.
//
// Args:
//   irsend:   A pointer to a IRsend object to transmit via.
//   ir_type:  enum of the protocol to be sent.
//   code:     Numeric payload of the IR message. Most protocols use this.
//   code_str: The unparsed code to be sent. Used by complex protocol encodings.
//   bits:     Nr. of bits in the protocol. 0 means use the protocol's default.
//   repeat:   Nr. of times the message is to be repeated. (Not all protcols.)
// Returns:
//   bool: Successfully sent or not.
bool sendIRCode(IRsend *irsend, decode_type_t const ir_type,
                uint64_t const code, char const * code_str, uint16_t bits,
                uint16_t repeat) {
  if (irsend == NULL) return false;
  bool success = true;  // Assume success.
  //  blinkity(2, 1); //ADD BY HUEX
  // Ensure we have enough repeats.
  repeat = std::max(IRsend::minRepeats(ir_type), repeat);
  if (bits == 0) bits = IRsend::defaultBits(ir_type);
  // Create a pseudo-lock so we don't try to send two codes at the same time.
  while (lockIr)
    delay(20);
  lockIr = true;


  // Turn off IR capture if we need to.
#if IR_RX && DISABLE_CAPTURE_WHILE_TRANSMITTING
  if (irrecv != NULL) irrecv->disableIRIn();  // Stop the IR receiver
#endif  // IR_RX && DISABLE_CAPTURE_WHILE_TRANSMITTING
  // send the IR message.
  switch (ir_type) {
#if SEND_PRONTO
    case decode_type_t::PRONTO:  // 25
      success = parseStringAndSendPronto(irsend, code_str, repeat);
      break;
#endif  // SEND_PRONTO
    case decode_type_t::RAW:  // 30
#if SEND_RAW
      success = parseStringAndSendRaw(irsend, code_str);
      break;
#endif
#if SEND_GLOBALCACHE
    case decode_type_t::GLOBALCACHE:  // 31
      success = parseStringAndSendGC(irsend, code_str);
      break;
#endif
    default:  // Everything else.
      if (hasACState(ir_type))  // protocols with > 64 bits
        success = parseStringAndSendAirCon(irsend, ir_type, code_str);
      else  // protocols with <= 64 bits
        success = irsend->send(ir_type, code, bits, repeat);
  }
#if IR_RX && DISABLE_CAPTURE_WHILE_TRANSMITTING
  // Turn IR capture back on if we need to.
  if (irrecv != NULL) irrecv->enableIRIn();  // Restart the receiver
#endif  // IR_RX && DISABLE_CAPTURE_WHILE_TRANSMITTING
  lastSendTime = millis();
  // Release the lock.
  lockIr = false;

  // Indicate that we sent the message or not.
  if (success) {
    sendReqCounter++;
    debug("Sent the IR message:");
  } else {
    debug("Failed to send IR Message:");
  }
  debug("Type:");
  debug(String(ir_type).c_str());
  // For "long" codes we basically repeat what we got.
  if (hasACState(ir_type) || ir_type == PRONTO || ir_type == RAW ||
      ir_type == GLOBALCACHE) {
    debug("Code: ");
    debug(code_str);
    // Confirm what we were asked to send was sent.
#if MQTT_ENABLE
    if (success) {
      if (ir_type == PRONTO && repeat > 0)
        mqtt_client.publish(MqttAck.c_str(), (String(ir_type) +
                                              kCommandDelimiter[0] + 'R' +
                                              String(repeat) +
                                              kCommandDelimiter[0] +
                                              String(code_str)).c_str());
      else
        mqtt_client.publish(MqttAck.c_str(), (String(ir_type) +
                                              kCommandDelimiter[0] +
                                              String(code_str)).c_str());
      mqttSentCounter++;
    }
#endif  // MQTT_ENABLE
  } else {  // For "short" codes, we break it down a bit more before we report.
    debug(("Code: 0x" + uint64ToString(code, 16)).c_str());
    debug(("Bits: " + String(bits)).c_str());
    debug(("Repeats: " + String(repeat)).c_str());
#if MQTT_ENABLE
    if (success) {
      mqtt_client.publish(MqttAck.c_str(), (String(ir_type) +
                                            kCommandDelimiter[0] +
                                            uint64ToString(code, 16) +
                                            kCommandDelimiter[0] +
                                            String(bits) +
                                            kCommandDelimiter[0] +
                                            String(repeat)).c_str());
      mqttSentCounter++;
    }
#endif  // MQTT_ENABLE
  }
  return success;
}
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

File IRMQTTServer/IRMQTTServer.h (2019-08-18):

/*
 * Send & receive arbitrary IR codes via a web server or MQTT.
 * Copyright David Conran 2016, 2017, 2018, 2019
 */
#ifndef EXAMPLES_IRMQTTSERVER_IRMQTTSERVER_H_
#define EXAMPLES_IRMQTTSERVER_IRMQTTSERVER_H_

#include <IRremoteESP8266.h>
#include <IRrecv.h>
#include <IRsend.h>
#include <IRtimer.h>
#include <IRutils.h>
#include <IRac.h>

// ---------------- Start of User Configuration Section ------------------------

#ifndef MQTT_ENABLE
#define MQTT_ENABLE true  // Whether or not MQTT is used at all.
#endif  // MQTT_ENABLE

#ifndef EXAMPLES_ENABLE
// Whether or not examples are included. `false` saves ~2.5K of program space.
#define EXAMPLES_ENABLE false
#endif  // EXAMPLES_ENABLE

// ---------------------- Board Related Settings -------------------------------
// NOTE: Make sure you set your Serial Monitor to the same speed.
#define BAUD_RATE 115200  // Serial port Baud rate.

// Change if you need multiple independent send gpios & topics. (MQTT only)
const uint8_t kNrOfIrTxGpios = 1;
// Default GPIO the IR LED is connected to/controlled by. GPIO 4 = D2.
// For an ESP-01 we suggest you use RX/GPIO3/Pin 7. i.e. kDefaultIrLed = 3
// Note: A value of -1 means unused.
const int8_t kDefaultIrLed = 4;  // <=- CHANGE_ME (optional)

// **DANGER** Optional flag to invert the output. (default = false)
//            `false`: The LED is illuminated when the GPIO is HIGH.
//            `true`: The LED is illuminated when GPIO is LOW rather than HIGH.
//            Setting this to something other than the default could
//            easily destroy your IR LED if you are overdriving it.
//            Unless you *REALLY* know what you are doing, don't change this.
const bool kInvertTxOutput = false;

// Default GPIO the IR demodulator is connected to/controlled by. GPIO 14 = D5.
const int8_t kDefaultIrRx = 14;  // <=- CHANGE_ME (optional)

// Enable/disable receiving/decoding IR messages entirely.
// Note: IR_RX costs about 40k+ of program memory.
#define IR_RX true

// Should we use PULLUP on the IR Rx gpio?
#define IR_RX_PULLUP false

// --------------------- Network Related Settings ------------------------------
const uint16_t kHttpPort = 80;  // The TCP port the HTTP server is listening on.
// Change to 'true'/'false' if you do/don't want these features or functions.
#define USE_STATIC_IP false  // Change to 'true' if you don't want to use DHCP.
// We obtain our network config via DHCP by default but allow an easy way to
// use a static IP config.
#if USE_STATIC_IP
const IPAddress kIPAddress = IPAddress(10, 0, 1, 78);
const IPAddress kGateway = IPAddress(10, 0, 1, 1);
const IPAddress kSubnetMask = IPAddress(255, 255, 255, 0);
#endif  // USE_STATIC_IP

// See: https://github.com/tzapu/WiFiManager#filter-networks for these settings.
#define HIDE_DUPLIATE_NETWORKS false  // Should WifiManager hide duplicate SSIDs
// #define MIN_SIGNAL_STRENGTH 20  // Minimum WiFi signal stength (percentage)
                                   // before we will connect.
                                   // The unset default is 8%.
                                   // (Uncomment to enable)
// Do you want/need mdns enabled? (https://en.wikipedia.org/wiki/Multicast_DNS)
#define MDNS_ENABLE true  // `false` to disable and save ~21k of program space.

// ----------------------- HTTP Related Settings -------------------------------
#define FIRMWARE_OTA true  // Allow remote update of the firmware via http.
                           // Less secure if enabled.
                           // Note: Firmware OTA is also disabled until
                           //       a password is set.
#define HTML_PASSWORD_ENABLE false  // Protect access to the HTML interface.
                                    // Note: OTA & GPIO updates are always
                                    //       passworded.
// If you do not set a password, Firmware OTA & GPIO updates will be blocked.

// ----------------------- MQTT Related Settings -------------------------------
#if MQTT_ENABLE
const uint32_t kMqttReconnectTime = 5000;  // Delay(ms) between reconnect tries.

#define MQTT_ACK "sent"  // Sub-topic we send back acknowledgements on.
#define MQTT_SEND "send"  // Sub-topic we get new commands from.
#define MQTT_RECV "received"  // Topic we send received IRs to.
#define MQTT_LOG "log"  // Topic we send log messages to.
#define MQTT_LWT "status"  // Topic for the Last Will & Testament.
#define MQTT_CLIMATE "ac"  // Sub-topic for the climate topics.
#define MQTT_CLIMATE_CMND "cmnd"  // Sub-topic for the climate command topics.
#define MQTT_CLIMATE_STAT "stat"  // Sub-topic for the climate stat topics.
// Enable sending/receiving climate via JSON. `true` cost ~5k of program space.
#define MQTT_CLIMATE_JSON false
// Do we send an IR message when we reboot and recover the existing A/C state?
// If set to `false` you may miss requested state changes while the ESP was
// down. If set to `true`, it will resend the previous desired state sent to the
// A/C. Depending on your circumstances, you may need to change this.
#define MQTT_CLIMATE_IR_SEND_ON_RESTART false
#define MQTTbroadcastInterval 10 * 60  // Seconds between rebroadcasts.

#define QOS 1  // MQTT broker should queue up any unreceived messages for us
// #define QOS 0  // MQTT broker WON'T queue up messages for us. Fire & Forget.
// Enable(true)/Disable(false) the option to send a MQTT Discovery message for
// the AirCon/Climate system to Home Assistant. `false` saves ~1.5k.
#define MQTT_DISCOVERY_ENABLE true
#endif  // MQTT_ENABLE

// ------------------------ IR Capture Settings --------------------------------
// Should we stop listening for IR messages when we send a message via IR?
// Set this to `true` if your IR demodulator is picking up self transmissions.
// Use `false` if it isn't or can't see the self-sent transmissions
// Using `true` may mean some incoming IR messages are lost or garbled.
// i.e. `false` is better if you can get away with it.
#define DISABLE_CAPTURE_WHILE_TRANSMITTING true
// Let's use a larger than normal buffer so we can handle AirCon remote codes.
const uint16_t kCaptureBufferSize = 1024;
#if DECODE_AC
// Some A/C units have gaps in their protocols of ~40ms. e.g. Kelvinator
// A value this large may swallow repeats of some protocols
const uint8_t kCaptureTimeout = 50;  // Milliseconds
#else  // DECODE_AC
// Suits most messages, while not swallowing many repeats.
const uint8_t kCaptureTimeout = 15;  // Milliseconds
#endif  // DECODE_AC
// Ignore unknown messages with <10 pulses (see also REPORT_UNKNOWNS)
const uint16_t kMinUnknownSize = 2 * 10;
#define REPORT_UNKNOWNS false  // Report inbound IR messages that we don't know.
#define REPORT_RAW_UNKNOWNS false  // Report the whole buffer, recommended:
                                   // MQTT_MAX_PACKET_SIZE of 1024 or more
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

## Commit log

2019-08-18 add code change
    add code change
    [CPPLINT.cfg, PIR v68.stl, PIR v69.stl]
2020-06-03 添加bom配置图文件
    添加bom配置图文件
2020-11-16 添加 homekit固件[仅8285 2M版本]
    该固件建议ESP8285 2M版本使用，1M版本更新后无法再刷机
